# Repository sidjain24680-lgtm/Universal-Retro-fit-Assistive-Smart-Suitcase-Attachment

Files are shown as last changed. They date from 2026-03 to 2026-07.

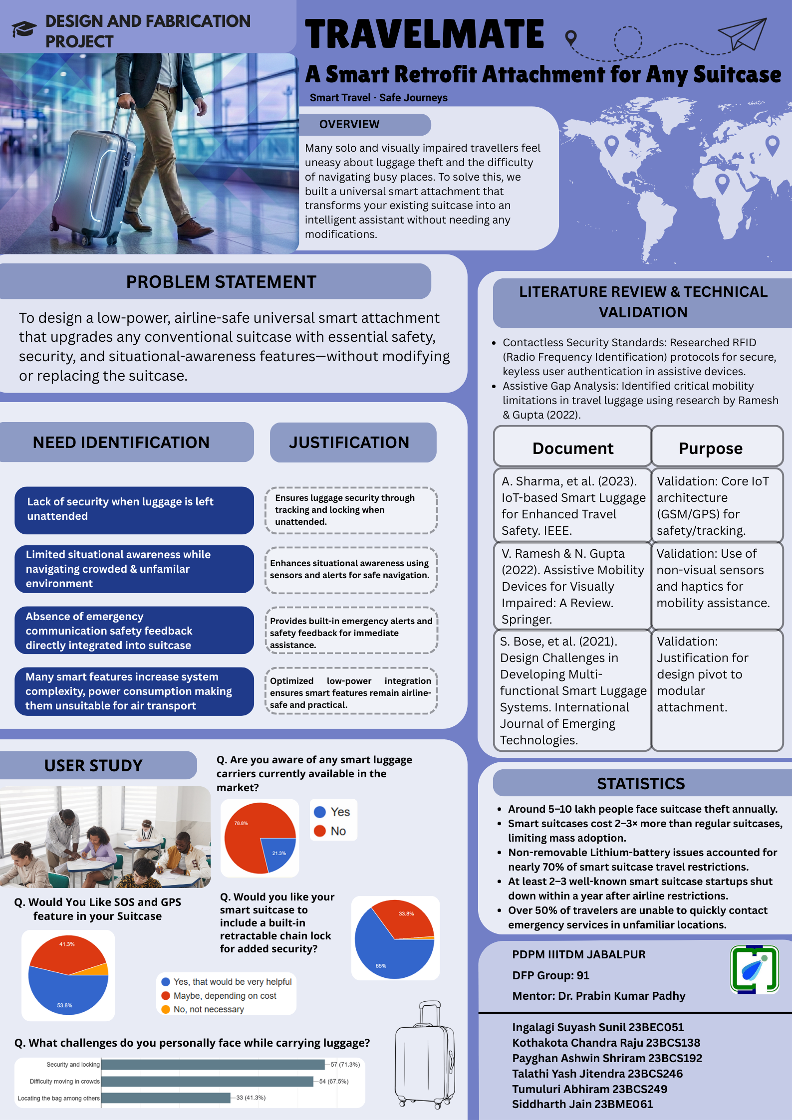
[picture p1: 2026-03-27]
Posters/Poster 1.png

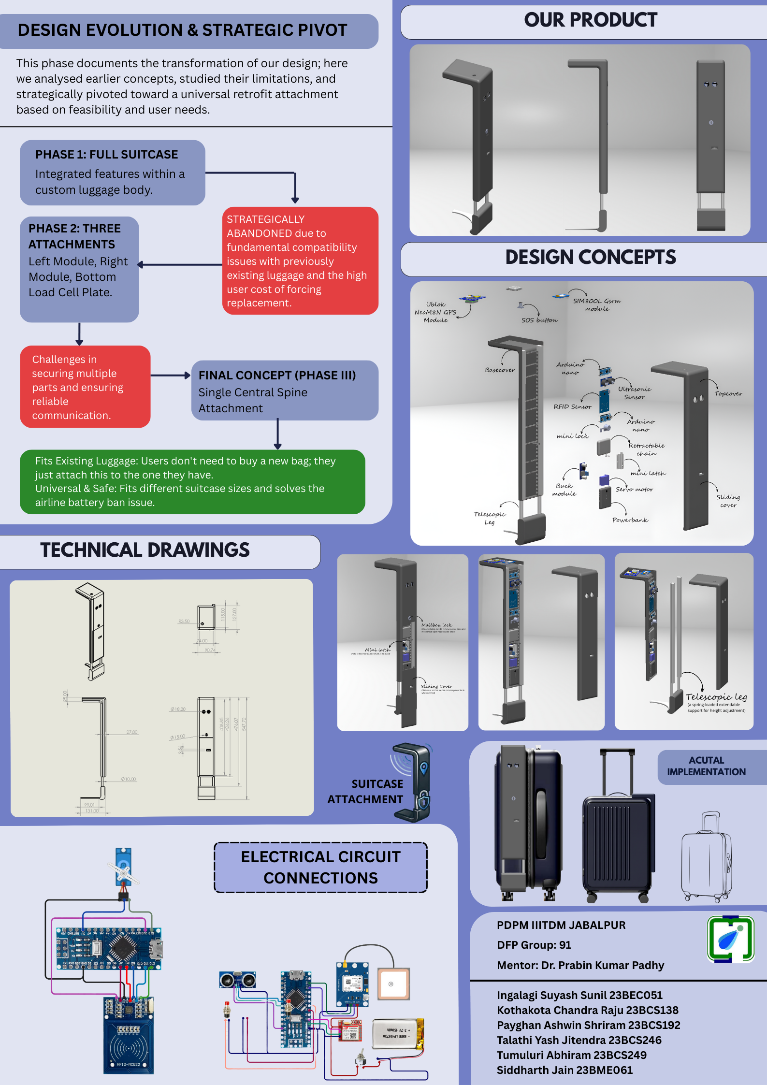
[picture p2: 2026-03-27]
Posters/Poster 2.png

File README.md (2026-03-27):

# Universal-Retro-fit-Assistive-Smart-Suitcase-Attachment

**1. Problem Statement**

Despite the evolution of travel gear, luggage remains a largely ”passive” asset. Travelers
face a significant gap between the need for high-tech security and the rigid, often-banned
designs of current smart suitcases. The core problems addressed by this project are:

- Safety Gap: Traditional suitcases offer no real-time theft prevention or tracking
    once they leave the traveler’s sight.
- Regulatory Conflict: Existing smart luggage often features non-removable lithium
    batteries, leading to bans by major airlines (IATA regulations).
- Exclusionary Design: Current luggage does not assist travelers with mobility or
    visual impairments.
- High Barrier to Entry: Smart features usually require purchasing a high-cost,
    integrated suitcase.

**2 Origin of the Idea: The Solo Travel Pain Points**

The concept was directly inspired by common frustrations encountered during solo and
independent travel:

- Security Anxiety: The need to temporarily secure luggage drove the requirement
    for a quick, reliable anti-theft chain system.
- Uncertainty and Stress: Obstacle detection and directional awareness were iden-
    tified as critical needs, leading to the development of an assistive walking aid.
- Weight Guesswork: The hassle of guessing baggage weight demanded an inte-
    grated, portable weight measurement solution.

**3 Industry Problem & Core Solution**

Here we studied common travel pain points, analysed failures in existing smart-luggage
products, and formulated the core problem that our solution aims to address.

```
Table 1: Case Study Highlights
Company Reason for Failure
BlueSmart Failed because the battery was non-removable, making the
product banned by major airlines. Users were forced to
buy a whole new smart suitcase, creating a high cost bar-
rier.
Raden Also shut down after airline bans due to embedded, non-
removable batteries. App-dependent design meant the
suitcase became unusable once the company closed.
```
Conclusion→ Our Thought Process
After analysing these failures, we realised that the real problems were battery regulations
and forcing users to purchase an entirely new suitcase. This led us to design a Universal
Retrofit Attachment that avoids these issues by being battery-removable, modular, and
compatible with any existing suitcase.

###### II Literature Review and Technical Validation

This phase validates our design choices by reviewing relevant research, technical papers,
and user studies, ensuring that every feature in the final concept is backed by proven
methods and established scientific understanding.

```
Document Purpose
Sharma, A., et al. (2023).
IoT-based Smart Lug-
gage for Enhanced Travel
Safety. IEEE.
```
```
Validation: Core IoT architecture (GSM/GPS) for
safety/tracking.
```
```
Ramesh, V. & Gupta, N.
(2022). Assistive Mo-
bility Devices for Visu-
ally Impaired: A Review.
Springer.
```
```
Validation: Use of sensors and feedback systems for
mobility assistance.
```
```
Bose, S., et al. (2021).
Design Challenges in De-
veloping Multi-functional
Smart Luggage Systems.
International Journal of
Emerging Technologies.
```
```
Validation: Justification for design pivot to modular
attachment.
```
```
User Study Google Form Capturing market interest and user pain points to val-
idate feature priority.
Design Mid sem Evalua-
tion PPT
```
```
Comprehensive overview of the design process and
current project standing.
```

##### III User Analysis

1 User Context Analysis (General Market)

- Demographics: The majority of respondents (70%) do not have a direct connec-
    tion to visual impairment, indicating the core market is the general public.
- Travel Habits: The user base is active, with 78.8% traveling either occasionally
    or frequently.
- Market Opportunity: There is a significant gap in the current market. 78.8%
    of users are unaware of any smart luggage carriers currently available, suggesting a
    ”Blue Ocean” opportunity for a general-purpose smart suitcase.

2 Universal User Problems (Core Market Drivers)

These are the friction points identified by the general population (the 70% majority) that
the main product must solve:

- Security Anxiety (Top Priority): 71.3% of users cited ”Security and locking”
    as a major challenge. This validates the need for robust, tech-enabled locking
    mechanisms for all travelers.
- Physical Strain: 65% of users struggle with ”Heavy weight,” and 67.5% find it
    difficult to move in crowds. This points to a need for ergonomic design and weight
    management features for the mass market.
- Asset Recovery: 41.3% struggle with locating their bag among others (e.g., at
    baggage claim), driving the need for distinct identification or tracking.

3 User Requirement Mapping

```
Feature Market De-
mand
```
```
General User Ben-
efit
```
```
Inclusivity Benefit
```
```
SOS Emergency 91.7% Yes Personal safety. Critical lifeline for dis-
abled users.
GPS Tracking 82.5% High Rat-
ing
```
```
Anti-theft recovery. Locating misplaced
luggage.
Weight Sensing 53.8% Helpful Avoiding airline fees. Checking weight with-
out scale.
Retractable Lock 65% Yes Quick security. Easy securing without
keys.
```

4 Strategic Conclusion

The data suggests a product strategy where Safety (SOS) and Tracking (GPS) are the
headline features for the mass market, while the Tactile/Audio Feedback and Handle
Integration are marketed as ”Universal Design” features that enhance convenience for
everyone while making the product fully accessible to visually impaired users.

##### IV Design Description and System Configuration

The final design of the project is a universal smart retrofit attachment intended to be
mounted externally on any conventional suitcase. The design prioritizes compatibility,
modularity, airline safety compliance, and cost efficiency, while integrating essential smart
features such as tracking, security, and assistive navigation.

1 Design Evolution Overview

The design process evolved through multiple conceptual stages. The initial approach
focused on developing a fully integrated smart suitcase; however, this concept was dis-
carded due to high manufacturing costs, airline battery restrictions, and the requirement
for users to replace existing luggage.
The second iteration explored a multi-attachment architecture consisting of separate
left, right, and bottom modules. Although this configuration allowed feature distribution,
it introduced challenges related to mechanical stability, communication reliability, and
installation complexity.
Based on these limitations, the final design converged on a single central spine at-
tachment, which consolidates all functionalities into one unified module. This approach
significantly improves ease of installation, structural integrity, and user acceptance.

2 Final Product Form Factor

The finalized product adopts a slim, vertical L-shaped profile that aligns with the front
surface of a suitcase. The design ensures minimal obstruction to user handling while
maintaining adequate internal volume for electronics and mechanical systems.
Key external features include:

- A compact top section housing the GPS module and antenna.
- A vertical spine containing the electronic control units and communication modules.
- A bottom section integrating the locking mechanism and retractable chain.

The attachment is designed to be non-invasive, requiring no drilling or permanent modi-
fication to the suitcase.

3 Internal Component Layout

The internal architecture is carefully organized to optimize space utilization and func-
tional separation:

- Upper Section: Houses the GPS module and antenna to ensure reliable signal
    reception.
- Middle Section: Contains the Arduino Nano microcontrollers, power regulation
    circuitry, and communication modules (GSM).
- Lower Section: Integrates the RFID module, servo-controlled locking system, and
    retractable chain mechanism.

This structured arrangement improves thermal management, reduces electromagnetic
interference, and simplifies maintenance.

4 Locking and Security Design

The security system employs an RFID-authenticated servo-controlled locking mechanism.
Upon successful RFID verification, the servo actuates the mechanical lock, allowing con-
trolled release or securing of the retractable chain. A manual override is included to
ensure reliability in case of electronic failure. This dual-mode locking approach balances
digital security with mechanical robustness.

5 Assistive Navigation Design

An ultrasonic sensor mounted on the attachment continuously monitors the surrounding
environment. When obstacles are detected within a predefined range, the system triggers
audible alerts through a buzzer, enabling safer navigation in crowded or unfamiliar spaces.
This feature is particularly beneficial for visually impaired and elderly users.

6 Technical Drawings and CAD Integration

Detailed technical drawings and CAD models were developed to define precise dimensions,
component placement, and mounting features. The CAD models also facilitated 3D
printing of the enclosure, allowing rapid prototyping, iterative refinement, and accurate
alignment of mechanical and electronic components. The final CAD-based design ensures
manufacturability, structural stability, and aesthetic consistency.

7 Implementation Readiness

The final design reflects a balance between functionality, feasibility, and user-centric
design. By consolidating multiple smart features into a single, attachable module, the
system achieves universality, regulatory compliance, and cost efficiency while remaining
scalable for future enhancements.

###### V Design Evolution and Strategic Pivot

This phase documents the transformation of our design; here we analysed earlier concepts,
studied their limitations, and strategically pivoted toward a universal retrofit attachment
based on feasibility and user needs.

```
Phase Concept Rationale for Final Pivot
Phase 1: Full
Suitcase
```
```
Integrated features within
a custom luggage body.
```
```
STRATEGICALLY ABAN-
DONED due to fundamental
compatibility issues with previ-
ously existing luggage and the high
user cost of forcing replacement.
Phase 2: Three
Attachments
```
```
Left Module, Right Mod-
ule, Bottom Load Cell
Plate.
```
```
Challenges in securing multiple
parts and ensuring reliable commu-
nication.
Final Concept
(Phase III)
```
```
Single Central Spine At-
tachment
```
```
Fits Existing Luggage: Users don’t
need to buy a new bag; they just at-
tach this to the one they have. Uni-
versal & Safe: Fits different suitcase
sizes and solves the airline battery
ban issue.
```
```
Pros and Cons of Single Attachment
```
- Pros: Unique and complete market ready product; Easy to Design and fabricate as
    compared to full suitcase; Takes lesser time to design and manufacture; Universal
    design gives our project an extra edge; novelty in design as retrofit attachment.
- Cons: It may not be securely fixed on the suitcase; challenges in prevention of
    disconnection if the bag falls.

##### VI Decision History and Technical Pivots

Throughout the development process, the project underwent several key design and tech-
nical pivots driven by cost feasibility, user accessibility, and practical implementation
constraints.

- Initial Concept: Full Smart Suitcase: The project initially began as the design
    of a fully integrated smart suitcase. However, this approach significantly increased
    the overall cost and required users to purchase an entirely new suitcase, even if
    they already owned one. This created a high entry barrier and reduced real-world
    adoption potential.
- Transition to a Retrofit Attachment: To address these limitations, the concept
    was shifted to a universal retrofit attachment that could be mounted on existing
    suitcases. During this phase, additional features such as weight measurement us-
    ing load cells were explored. However, the weight-measurement module was later
    removed to maintain a slim form factor, reduce mechanical complexity, and ensure
    universal compatibility across different suitcase types. This strategic pivot reduced
    the estimated system cost from approximately 45,000–50,000 to 4,000–5,000, mak-
    ing the solution significantly more affordable and practical for end users.
- Evolution of the Locking Mechanism: The locking system also evolved through
    multiple stages. The initial idea involved app-based digital locking, which was
    later discarded due to increased software dependency and reliability concerns. The
    design then moved to RFID-based authentication, offering secure, contactless access
    without requiring a smartphone. During prototyping, solenoid-based locking was
    tested but later replaced with a servo-controlled locking mechanism, as the servo
    provided smoother operation, lower power consumption, and better mechanical
    reliability. A manual locking option was retained as a physical override for added
    safety.
- Circuit and Connectivity Simplification: Initially, wireless connectivity using
    ESP-based modules was considered. However, since the required communication
    could be handled using GSM for alerts and GPS for tracking, the ESP module was
    removed to simplify the circuit, reduce power consumption, and minimize system
    complexity.
- Final CAD-Based System Integration: After finalizing the hardware architec-
    ture, the complete system was implemented and organized within a custom CAD-
    designed enclosure, enabling precise component placement, efficient wiring, and a
    compact, universal form factor suitable for fabrication.

#### VII Electrical Connections and Power Architecture

This section describes the electrical interconnections and power architecture. The system
is designed with a modular wiring strategy to ensure reliability, ease of maintenance, and
compact integration.

1 Microcontroller Configuration

The system uses two Arduino Nano microcontrollers as the primary control units.

- Controller 1 (Security & Locking): Handles RFID authentication, servo motor
    control, and retractable chain locking operations.
- Controller 2 (Navigation & Communication): Manages ultrasonic sensing,
    GPS location tracking, GSM communication, SOS alerts, and buzzer activation.

Both microcontrollers operate with a shared common ground to ensure stable signal
referencing across all connected modules.

2 RFID Locking System Connections

The RFID module is interfaced with the Arduino Nano using digital communication
pins. Power connections are provided through the regulated supply and common ground.
Upon successful RFID authentication, a control signal is sent to the servo motor, which
mechanically actuates the door lock and releases or secures the retractable chain. This
enables contactless, secure access control without the need for mechanical keys.

3 Servo Motor and Lock Actuation

The servo motor is connected to a PWM-enabled digital pin of the Arduino Nano. It
receives sufficient current from the power system to ensure reliable actuation. The servo’s
rotational motion is mechanically linked to the door lock, converting electronic control
into physical locking and unlocking action.

4 Ultrasonic Sensor Interface

The ultrasonic sensor is connected using dedicated trigger and echo pins. The trigger
pin emits ultrasonic pulses. The echo pin receives reflected signals, allowing distance
calculation. This data is processed in real time to detect obstacles and provide situational
awareness, especially useful in crowded or unfamiliar environments.

5 GPS Module Connections

The Ublox NEO-6M GPS module is connected to the microcontroller via serial communi-
cation (TX/RX). It continuously provides latitude and longitude coordinates. The GPS
antenna is positioned away from metallic components to ensure stable signal reception.
The location data is used for real-time tracking and emergency alerts.

6 GSM Module Integration

The SIM800L GSM module is interfaced using serial communication lines. It is powered
directly from the main power source due to its higher current demand during transmission.
The module is used to send SOS messages and location updates to predefined contacts
during emergency events.

7 Buzzer and Alert Outputs

A buzzer is connected to a digital output pin of the Arduino Nano. It provides audible
alerts for obstacle proximity, system status notifications, and emergency feedback. Alert
patterns are controlled through embedded software logic.

8 Power Supply Strategy

- Current Prototype Power Source: At the prototyping stage, the system is
    powered using a 3.7 V rechargeable Li-ion battery. Enables compact integration
    and easy testing. Supplies power to all modules through regulated voltage lines. A
    power switch is included for safe operation.
- Planned Final Power Source (Design Upgrade): In the final implementation,
    the fixed battery will be replaced with a removable power bank–based power source.
    This upgrade provides: Airline safety compliance through removable battery design;
    User convenience, allowing easy charging and replacement; Extended operational
    time due to higher capacity; Modular power replacement aligned with the retrofit
    design philosophy. A voltage regulation circuit will step down the power bank
    output to meet system voltage requirements.

9 Wiring and Prototyping Method

During development, all electrical connections are implemented using jumper wires,
switches, and a breadboard. This approach: Enables rapid prototyping and debugging;
Allows flexible circuit modification; Supports iterative testing before final enclosure inte-
gration.

### VIII Detailed Mechanical Design & Internal Architecture

1 The Central Spine Structure

The attachment is designed as a single-piece L-shaped unified enclosure (approx. 400mm
x 70mm x 22mm).

- Top Cap: Houses the GPS system and ceramic antenna behind an RF-transparent
    polycarbonate window.
- Vertical Spine: The main body housing all electronics, GSM module, and the
    retractable chain reel.
- Telescopic Bottom: Uses brushed aluminum rods and internal springs to create a
    ”clamping effect” that adapts to suitcase heights from cabin bags to large check-ins.

2 Universal Clamping & Mounting

The device achieves a ”zero-modification” fit through three principles:

- Curvature-Adaptive Pads: Soft TPU and foam composite pads on the rear
    surface conform to the suitcase’s shape (hard-shell or fabric).
- Spring-Assisted Tension: Telescopic rods ensure a snug vertical fit.
- Secondary Nylon Strap: A high-quality webbing strap with a hidden stainless
    steel cam buckle loops around the suitcase for absolute rotational stability.

3 Internal Architecture & Component Placement

The 400 mm spine is internally divided into precise compartments:

- Top GPS Section: Located inside the top cap: GPS module with ceramic an-
    tenna, RF-transparent polycarbonate window, 25 mm RF-clearance zone, Isolated
    from metal parts to improve signal quality.
- Electronics & Logic Section (Upper-Mid Spine): Contains: Arduino Nano
    microcontrollers, Sensor connectors, Power regulation circuitry, Ventilation slots for
    GSM heat dissipation.
- GSM Communication Section: Situated centrally: GSM module, SIM card
    tray accessible via side flap, Antenna passage to maintain signal clarity.

- Retractable Chain Section: Lower-mid spine zone: Chain reel cavity (50-55 mm
    diameter), High-strength retractable wire, Spring-loaded mechanism for automatic
    retraction.
- Locking Section: At the spine’s lower end: Housing for the Servo motor and
    Door Lock mechanism, RFID Module for secure chain release, Mechanical override
    capability.
- Telescopic Rod Housing: At the very bottom: Guide channels for the rods,
    Reinforced rib structure, Smooth low-friction bushings.

4 Specialized Mechanisms (Snap-Fit Design)

Every electronic component is housed in precisely designed snap-fit compartments. These
compartments utilize flexible locking tabs and arrow-shaped clips to secure modules with-
out the need for screws. This method ensures clean internal organization, prevents rat-
tling during transit, and allows for modular replacement of parts.

- Anti-Theft Chain: A spring-loaded reel with a retractable chain. It docks into a
    cavity containing a dual-locking system featuring an RFID-controlled servo mech-
    anism and a robust door lock.
- Obstacle Alert System: Ultrasonic sensors and a buzzer provide clear distance-
    based alerts to the user, particularly useful for visually impaired travelers.

##### IX Materials and Fabrication Strategy

1 Material Selection

- Enclosure: PC-ABS for a balance of rigidity and impact toughness.
- Telescopic Rods: Lightweight 6061 Aluminum for smooth sliding and structural
    strength.
- Contact Surfaces: Overmolded TPU (Shore A 20-40) to prevent scratching the
    suitcase.
- RF Window: Clear Polycarbonate for the GPS module to ensure maximum signal
    sensitivity.

2 Manufacturing Phases

- Prototyping: 3D printing (ABS/PETG) for the main body, using brass heat-set
    inserts for durable assembly.

- Production: Injection molding for the main shell with ultrasonic welding for in-
    ternal assembly. CNC machining for the aluminum telescopic guide rods.

###### X Software Architecture & Logic Flow

The system operates on a prioritized polling architecture controlled by the dual Arduino
Nano setup:

- Priority Interrupts: The SOS push-button is tied to a hardware interrupt, en-
    suring that emergency location coordinates are transmitted via GSM immediately,
    regardless of other processes.
- Sensor Fusion: The ultrasonic sensors operate in a continuous loop. When dis-
    tance falls below 50cm, the buzzer frequency increases to provide ”proximity-aware”
    audio feedback.
- Security Protocol: The RFID module stays in a low-power listening state. Upon
    a valid tag scan, the Servo motor triggers the mechanical latch to release or lock
    the retractable chain.
- Power Management: The system utilizes ”Deep Sleep” cycles when the GPS
    accelerometer (built-in) detects no movement for over 10 minutes, significantly ex-
    tending battery life.

##### XI User Interaction & Workflow

- Installation: Place attachment on the front side of the suitcase near the zipper.
    Extend bottom rods to reach the lower curvature. Tighten strap behind the suitcase
    using hidden cam buckle.
- During Travel: GPS keeps tracking suitcase. GSM stays ready for SOS messages.
    Sensors detect obstacles and trigger alerts.
- Security Use: Chain is deployed when leaving luggage unattended. Chain docks
    into the lock.
- Power: Battery can be removed and recharged externally. Power consumption is
    optimized through deep sleep cycles.

#### XII Component Finalization and Estimated Cost

The following breakdown details the Bill of Materials required for the fabrication of the
prototype.

```
S. No. Component Name Quantity Cost ()
1 Arduino Nano 2 658
2 Servo motor 1 99
3 RFID Module 1 150
4 Retractable Chain 1 300
5 Door Lock 1 300
6 UBlox NEO-6m GPS Module 1 520
7 Sim 800L GSM GPS Module 1 299
8 3.7 V Battery 2 258
9 Ultrasonic Sensors 1 61
10 Buzzer 1 34
11 3D Printing/ Fabrication - 2000
12 Wires, switches, breadboard - 411
Grand Total 5090
```
### XIII Market Feasibility & Business Model

This section evaluates the commercial viability, target market, cost feasibility, and long-
term sustainability. The objective is to demonstrate that the proposed solution is not
only technically sound but also economically practical and scalable.

1 Market Need Analysis

The global travel accessories market has grown rapidly due to increased solo travel, budget
airlines, and international mobility. However, smart luggage adoption remains limited due
to regulatory bans, high costs, and lack of universality.
Identified Market Gaps

- Airline bans on non-removable battery smart suitcases.
- High entry cost (20,000–50,000) for integrated smart luggage.
- Lack of physical theft prevention in existing trackers.
- No accessibility-focused luggage solutions.
- Dependency on proprietary mobile apps.

Our project directly addresses these gaps by offering a universal, removable, regulation-
compliant retrofit attachment that transforms any ordinary suitcase into a smart suitcase.

2 Target Customer Segments

The product is designed for multiple user groups, expanding its potential market reach:

- Primary Users: Solo Travelers & Backpackers: High concern for luggage safety;
    frequent use of public transport, hostels, and shared spaces. International Travelers:
    Airline compliance is critical; need for real-time tracking and SOS features.
- Secondary Users: Elderly Travelers: Benefit from obstacle detection and assistive
    alerts. Visually Impaired Travelers: Audible proximity alerts provide navigation
    assistance. Students & Budget Travelers: Cannot afford expensive smart suitcases;
    prefer upgrading existing luggage.
- Institutional Buyers (Future Scope): Airports, Travel tour operators, Railway
    & bus terminals, Travel safety programs.

3 Market Size & Opportunity

Even conservative estimates show strong feasibility:

- Millions of travelers already own standard luggage.
- A retrofit attachment targets an existing installed base.
- There is no need to convince users to replace their suitcase.

This gives the product a much larger addressable market than full smart suitcases.

4 Competitive Advantage

```
Parameter Existing Smart Suitcases GPS Trackers Proposed Attachment
Airline-compliant bat-
tery
```
```
No Yes Yes
```
```
Physical anti-theft No No Yes
Universal compatibil-
ity
```
```
No Yes Yes
```
```
Accessibility features No No Yes
One-time hardware
cost
```
```
No Yes Yes
```
```
App dependency High Medium Low (SMS-based)
```
Key Differentiator: This is the only solution combining GPS tracking, physical anti-
theft, and assistive navigation in a removable, airline-safe form factor.

5 Cost Feasibility Analysis

- Prototype Cost Summary: Total prototype cost: 5,
- Estimated Mass Production Cost: With bulk manufacturing, we anticipate:
    Electronics cost reduction: 25–30%; Switching to injection molding instead of 3D
    printing; Simplified assembly via snap-fit design. Estimated production cost (per
    unit): 2,500–3,

### XIV Sustainability & Environmental Impact

- E-Waste Mitigation: Traditional smart suitcases are discarded when electron-
    ics fail. Our retrofit design promotes the Circular Economy by allowing users to
    upgrade the tech without throwing away the luggage body.
- Modular Repairability: Components are housed in snap-fit compartments. If a
    sensor or battery fails, it can be replaced individually, extending the overall product
    lifecycle.

#### XV Novelty and Innovation

- Universal Retrofit Design: A standalone module that adds smart features to
    any suitcase without permanent structural changes.
- Cost-Efficient Tracking: Provides integrated GPS/SOS for 1,000, outperforming
    passive trackers like AirTag ( 3,000).
- Inclusive Navigation: Features ultrasonic sensors and audible alerts to assist
    visually impaired travelers.
- Retractable Security: The only system with an integrated, spring-loaded steel
    cable for physical anti-theft tethering.
- RFID Authentication: Utilizes RFID-controlled locking to ensure only autho-
    rized users can release the chain.
- Regulatory Compliance: Uses a removable battery design to bypass airline safety
    bans.

### XVI Future Scope

- AI Vision Integration: Replacing ultrasonic sensors with an ESP32-CAM to
    allow the walking aid to recognize specific objects (e.g., distinguishing a flight of
    stairs from a person).
- Solar Trickle-Charging: Integrating thin-film flexible solar cells onto the poly-
    carbonate top cap to recharge the module while the traveler walks outdoors.
- Dedicated Mobile App: Developing a custom interface to replace SMS com-
    mands with a map-based UI and biometric (Fingerprint/FaceID) chain unlocking.

## XVII Conclusion

This smart suitcase attachment successfully integrates mechanical engineering, industrial
design, electronics, and human-centered functionality into a single compact system. The
unique L-shaped form factor, telescopic adjustment mechanism, and universal strap-
based mounting approach allow it to adapt to almost any suitcase size or shape. With
its expandable set of smart features—GPS, SOS alerts, anti-theft locking, and obstacle
detection—it transforms ordinary luggage into a secure, connected, and assistive travel
tool. This device demonstrates an innovative approach to augmenting existing travel
equipment and represents a significant step toward inclusive, intelligent, and universally
compatible travel technology.

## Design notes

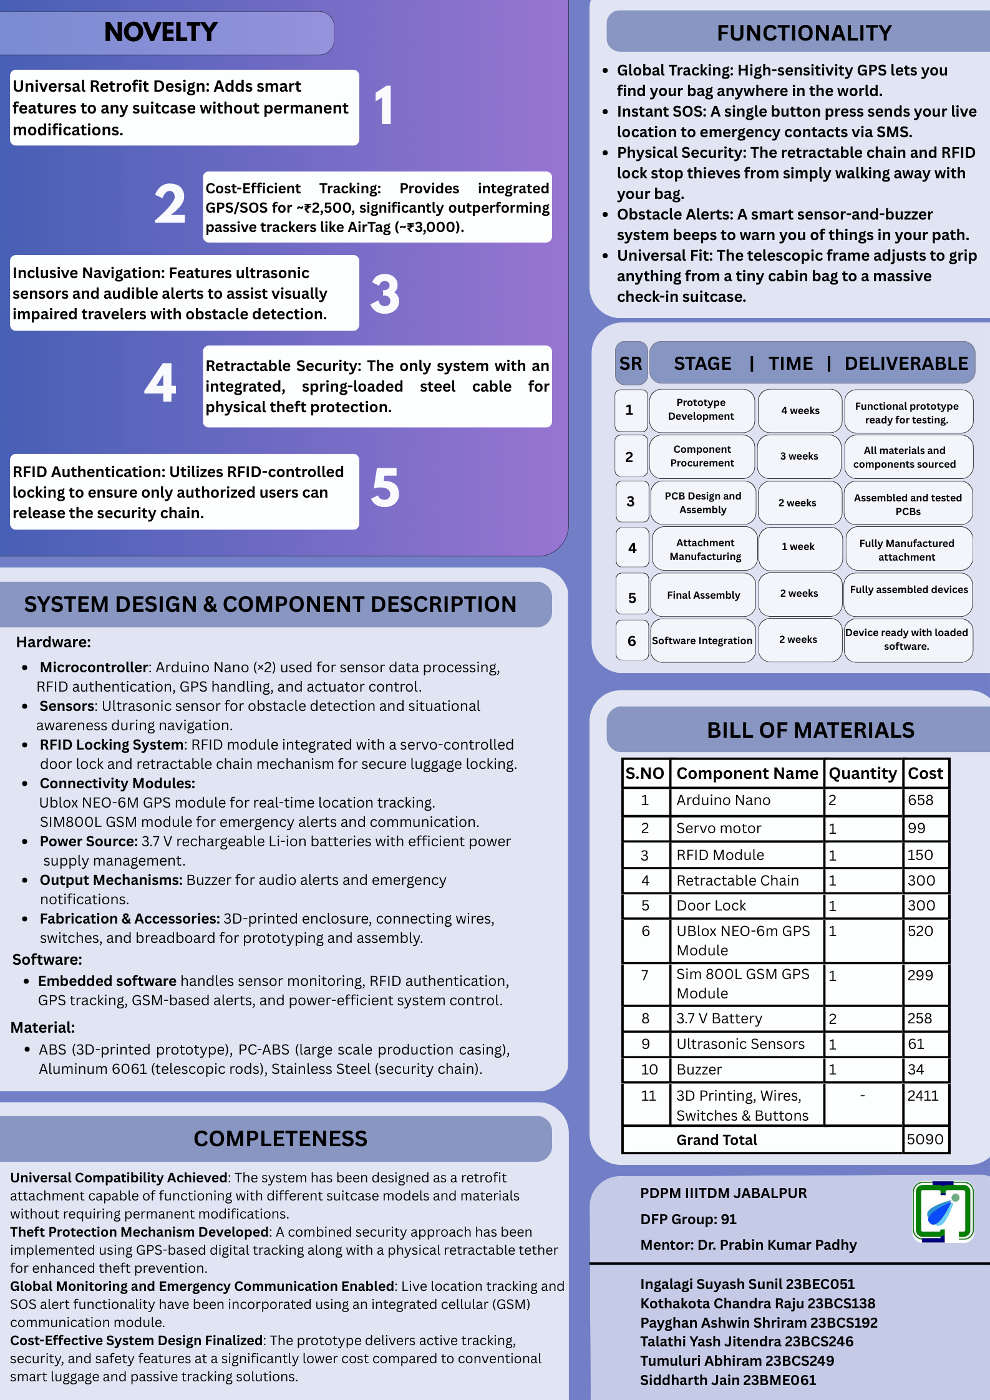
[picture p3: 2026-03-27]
Posters/Poster 3.png

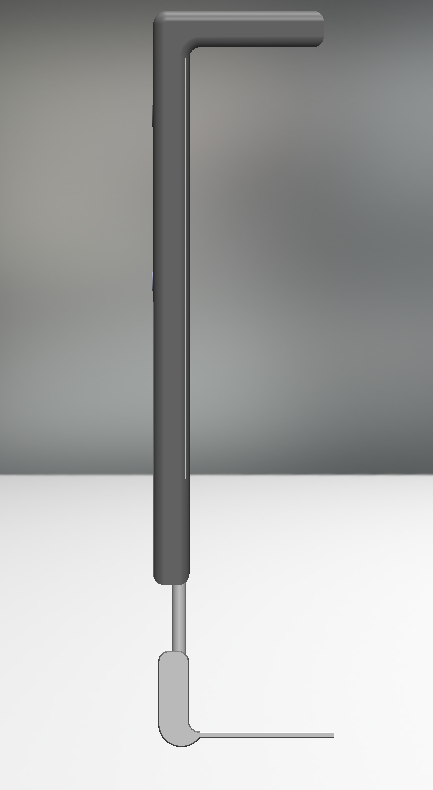
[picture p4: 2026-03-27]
Images/Side View 2.png

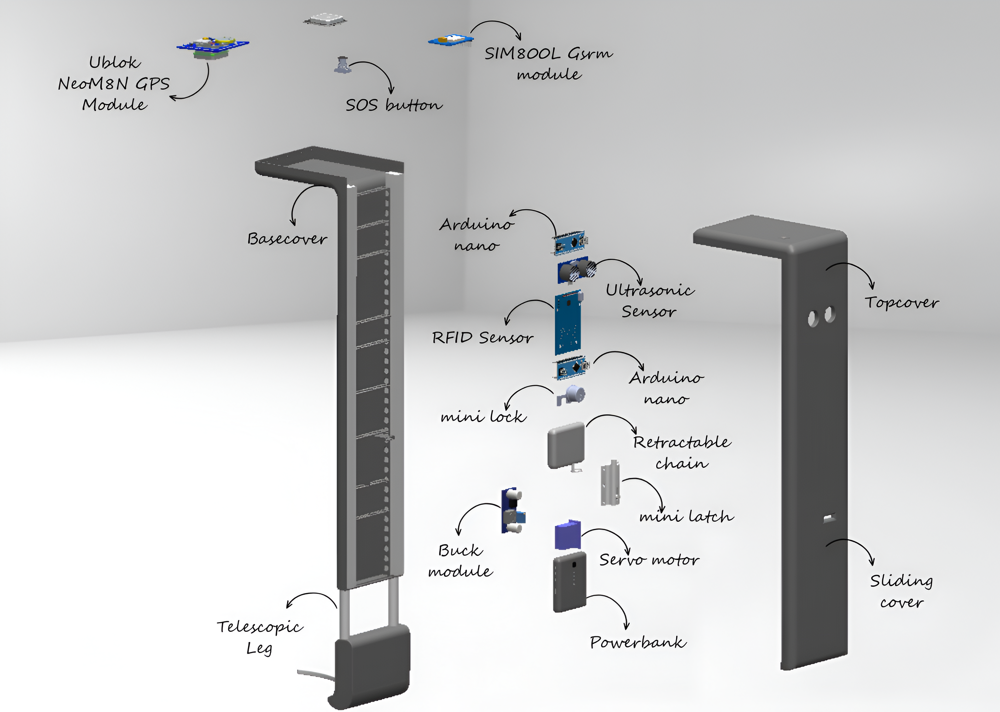
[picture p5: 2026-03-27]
Images/Exploaded View with Annotations.png

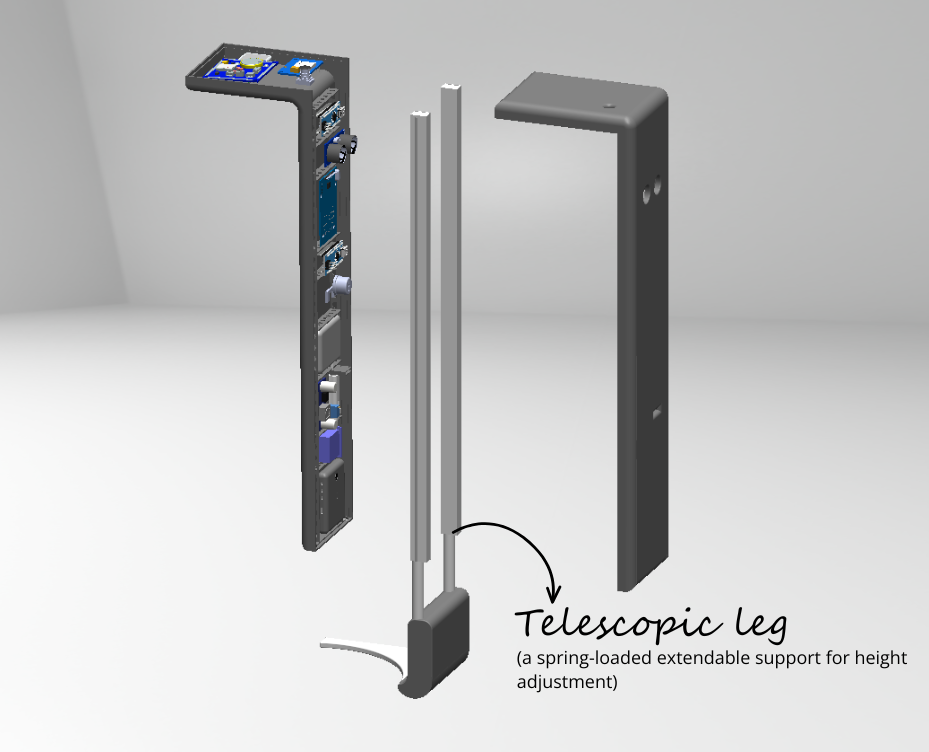
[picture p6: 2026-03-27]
Images/Ublok NeoM8N GPS Module (3).png

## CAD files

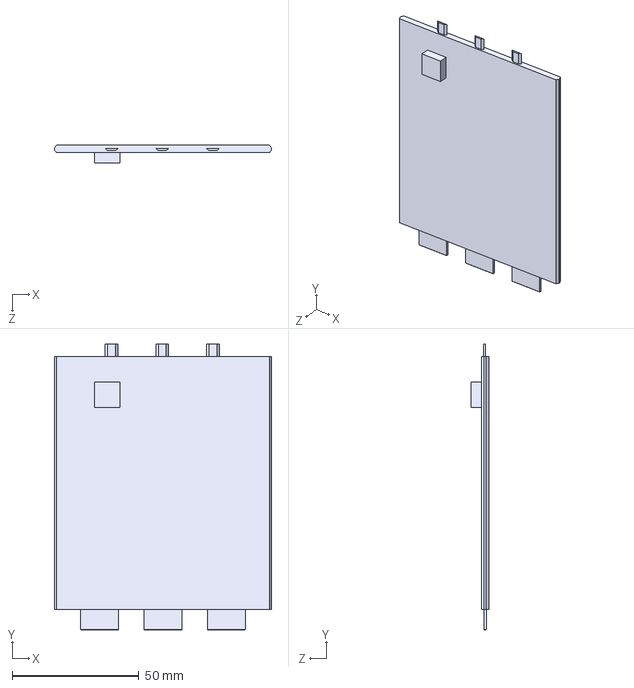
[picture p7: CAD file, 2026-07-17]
CAD Model/Dhakkan 1.STEP
85.6 x 112.8 x 7.00 mm

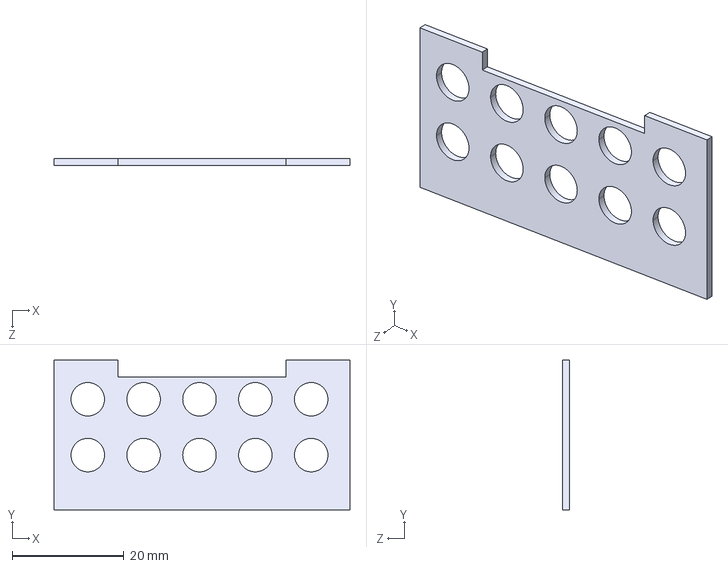
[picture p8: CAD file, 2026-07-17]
CAD Model/Partition.STEP
53.0 x 26.8 x 1.20 mm

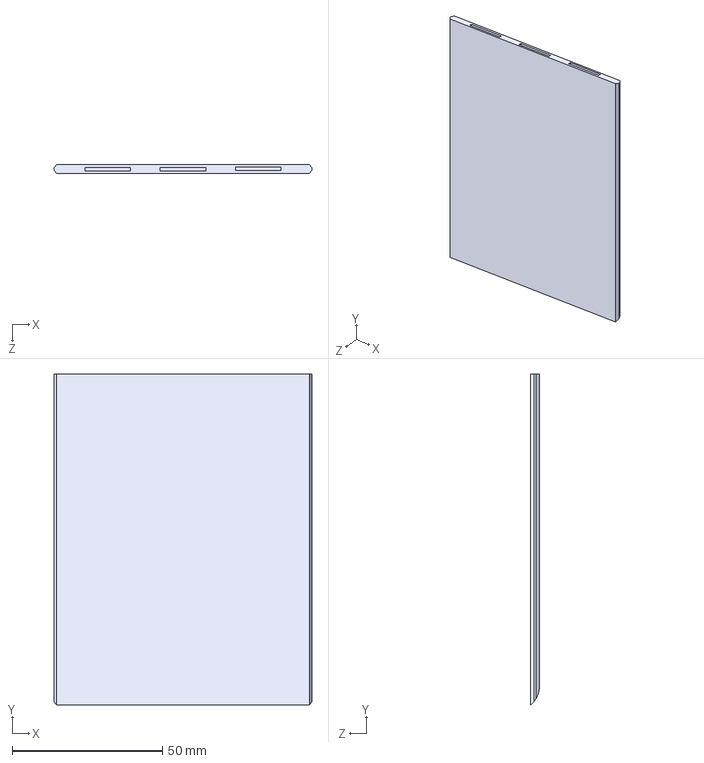
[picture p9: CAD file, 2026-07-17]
CAD Model/Dhakkan 2.STEP
85.6 x 110.0 x 3.00 mm

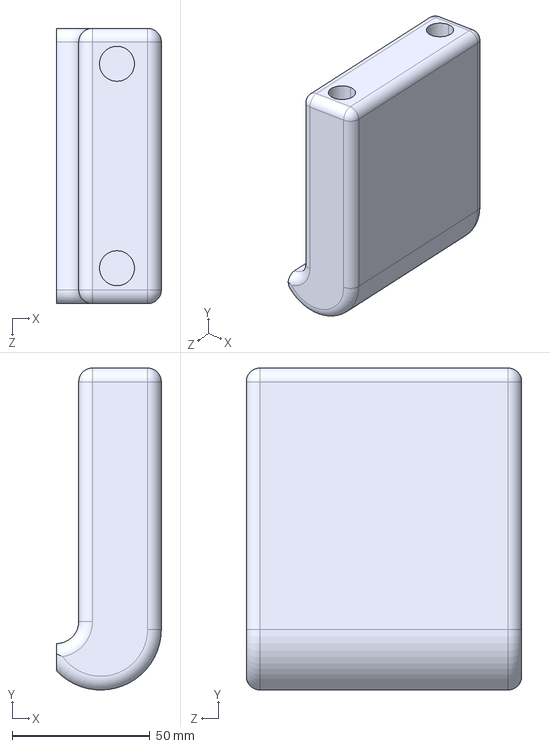
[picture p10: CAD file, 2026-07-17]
CAD Model/Bottom Support.STEP
38.0 x 116.9 x 100.0 mm

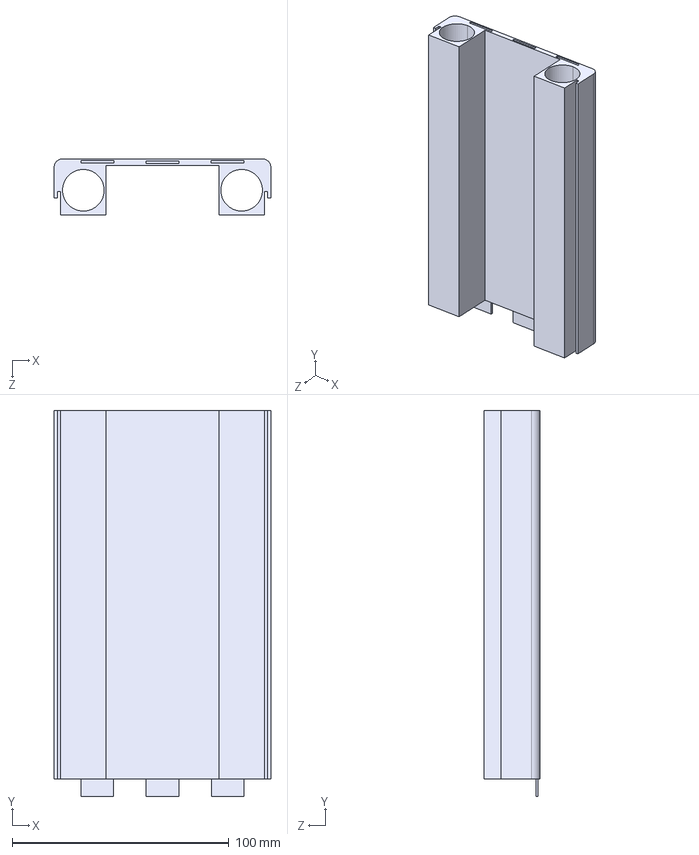
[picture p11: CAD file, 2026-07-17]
CAD Model/BASE 2.STEP
100.0 x 178.0 x 26.0 mm

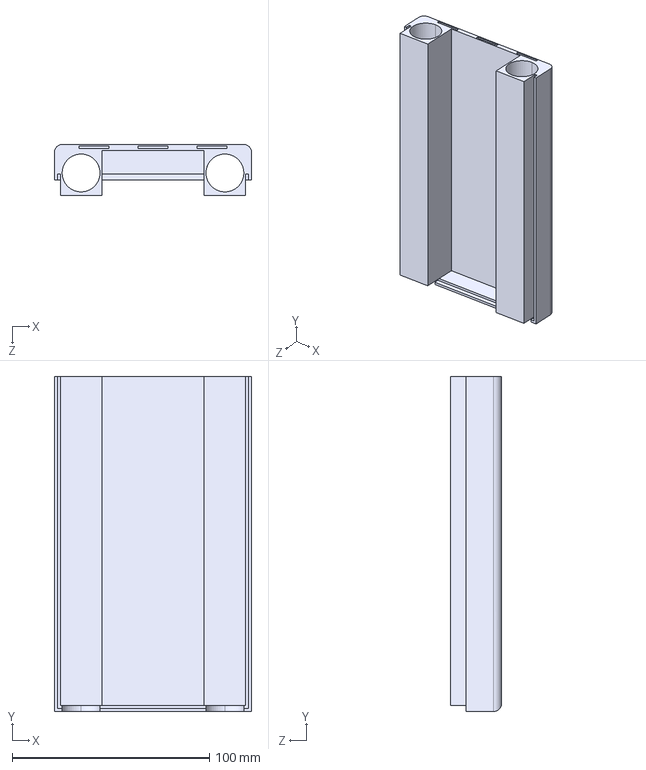
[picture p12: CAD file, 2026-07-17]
CAD Model/BASE 3.STEP
100.0 x 170.0 x 26.0 mm

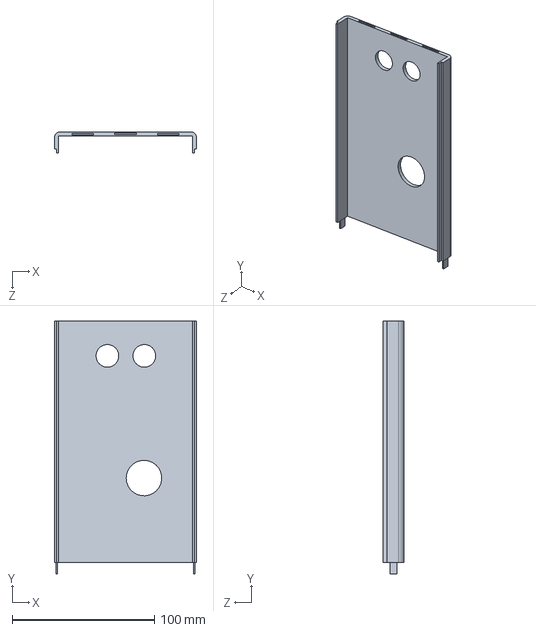
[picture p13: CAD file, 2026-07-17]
CAD Model/TOP Cover 2SLDPRT.SLDPRT
100.0 x 178.0 x 15.0 mm

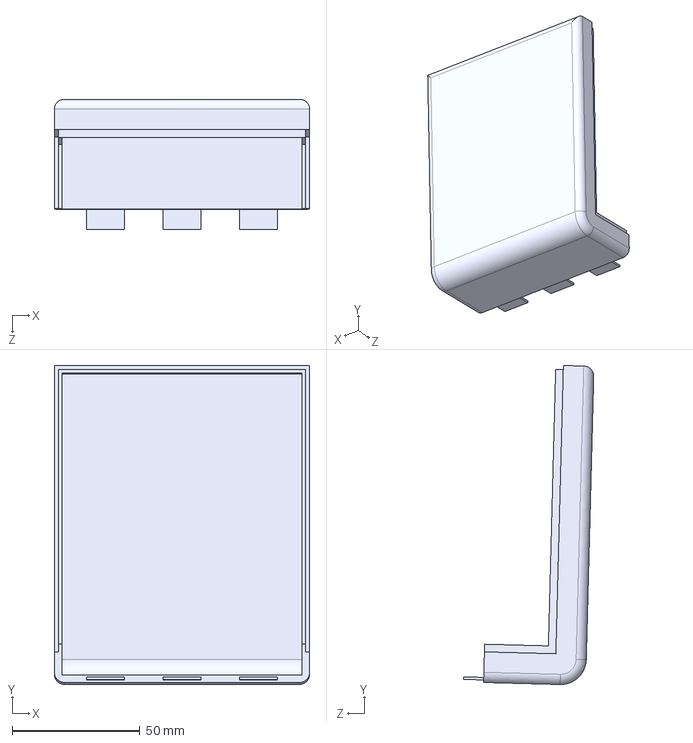
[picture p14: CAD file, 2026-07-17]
CAD Model/Top Cover 1.STEP
100.0 x 125.0 x 51.1 mm

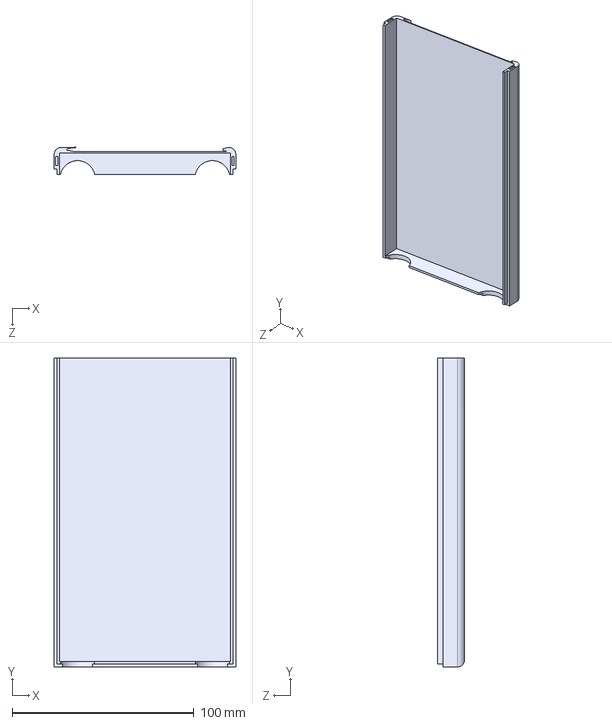
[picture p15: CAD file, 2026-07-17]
CAD Model/TOP Cover 3.STEP
100.0 x 170.0 x 15.0 mm

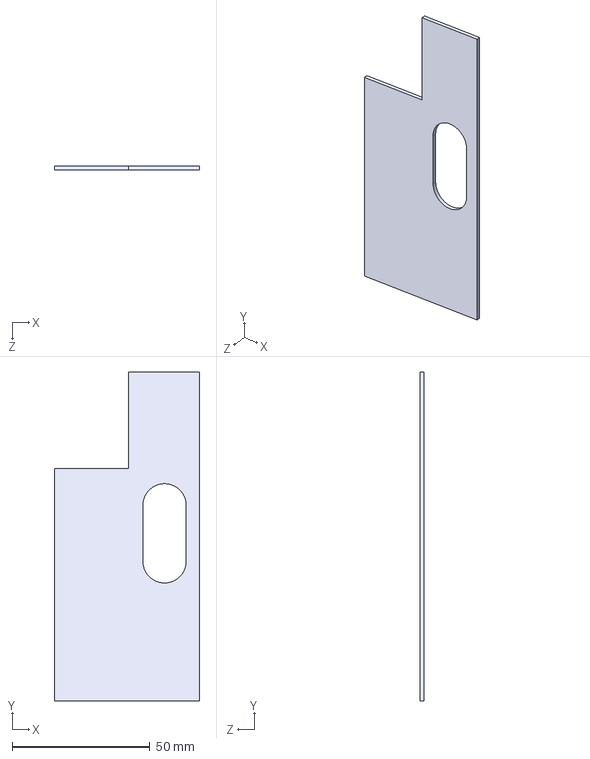
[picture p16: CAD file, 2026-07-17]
CAD Model/plate cover.STEP
52.8 x 119.6 x 1.60 mm

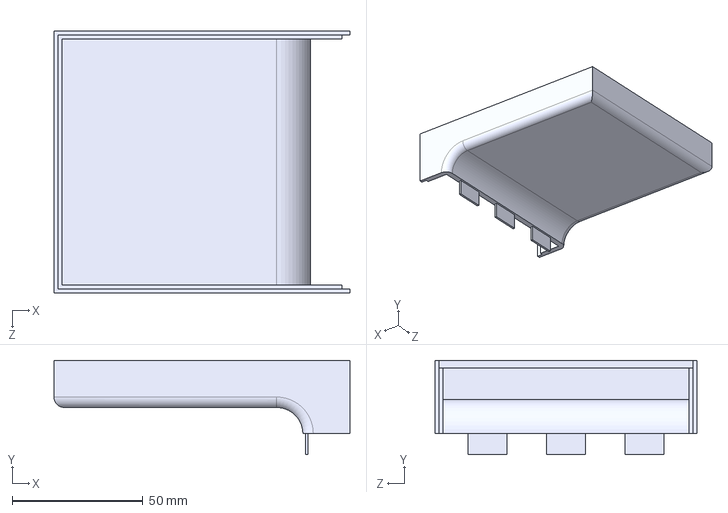
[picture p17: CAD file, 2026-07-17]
CAD Model/BASE 1.STEP
113.0 x 36.0 x 100.0 mm

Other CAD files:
CAD Model/TOP Cover 2.STEP
CAD Model/BASE 1.SLDPRT
CAD Model/BASE 2.SLDPRT
CAD Model/BASE 3.SLDPRT
CAD Model/Dhakkan 1.SLDPRT
CAD Model/Dhakkan 2.SLDPRT
CAD Model/TOP Cover 3.SLDPRT
CAD Model/Top Cover 1.SLDPRT
